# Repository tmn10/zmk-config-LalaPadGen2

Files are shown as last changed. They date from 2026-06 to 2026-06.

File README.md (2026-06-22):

# zmk-config-LalaPadGen2

LaLaPad Gen2 向け ZMK カスタムファームウェア設定。

---

## ハプティックフィードバック Mod

右トラックパッド下に DRV2605L + LRA を搭載し、ドラッグ開始・解除にクリック感を付与する。

### BOM

| 部品 | 型番 / 仕様 | 数量 | 備考 |
|---|---|---|---|
| LRA（横振動モーター） | JYLRA061228XH | 1 | 12×6×2.85mm、X軸、200Hz、定格 2.0V |
| ハプティックドライバ | DRV2605L | 1 | I2C 制御、アドレス 0x5A |
| 配線 | 細線（AWG30 相当） | 適量 | ケーブル引き回し穴（3×4mm）経由 |

### 配線

DRV2605L と Seeeduino XIAO BLE の接続：

| DRV2605L | XIAO BLE | 備考 |
|---|---|---|
| VDD | 3V3 | |
| GND | GND | |
| SDA | D4 (P0.26) | IQS9151 と I2C バス共有 |
| SCL | D5 (P0.27) | IQS9151 と I2C バス共有 |
| IN | GND | I2C モード使用のため不要 |
| OUT+ | LRA + | |
| OUT− | LRA − | |

IQS9151 IRQ ピン: XIAO D6 (P1.11)

### LRA ポケット寸法（3D プリント）

| 項目 | 値 |
|---|---|
| 内寸（L×W×D） | 12.2 × 6.2 × 2.8 mm |
| 底面厚 | 1.2 mm |
| ケーブル引き回し穴 | 3 × 4 mm |

各辺 0.1mm クリアランス（LRA 公称 12×6×2.85mm に対し深さ方向は 2.8mm で圧入気味）。

### 組み立てノート

- **ケース印刷**: リポジトリの `LRA_case.stl` を 3D プリントして使用する（推奨素材: PETG）
- **固定方法**: LRA ポケットの底面にカプトンテープを貼り、その上に両面テープで LRA を固定する
- **DRV2605L モジュール加工**: 基板上の FFC ケーブルコネクタは実装不要のため取り外してから使用すること

### ファームウェア設定

`lalapadgen2_right.overlay` の DRV2605L ノード：

```dts
drv2605: drv2605@5a {
    compatible = "ti,drv2605";
    reg = <0x5a>;
    actuator-type = "lra";
    rated-voltage-mv = <2000>;
    overdrive-voltage-mv = <2800>;
    library = <6>;
    status = "okay";
};
```

`lalapadgen2_right.conf` の主要ハプティック設定：

```conf
CONFIG_DRV2605=y
CONFIG_INPUT_IQS9151_HAPTIC_FEEDBACK_ENABLE=y
CONFIG_INPUT_IQS9151_HAPTIC_LONG_PRESS_EFFECT=6      # ドラッグ開始時
CONFIG_INPUT_IQS9151_HAPTIC_DRAG_LOCK_RELEASE_EFFECT=6  # ドラッグロック解除時
```

エフェクト番号は library 6（LRA）の 1〜117 から選択可能。`overdrive-voltage-mv` は XIAO BLE の 3.3V レール上限を超えないよう 3000mV 以下に抑えること。

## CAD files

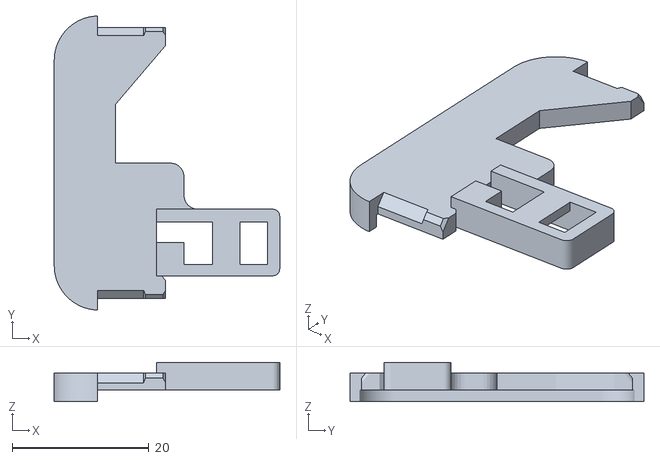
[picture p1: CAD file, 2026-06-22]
LRA_case.stl
33.0 x 43.0 x 5.71

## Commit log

2026-05-02 Disable USB logging due to conflict with studio-rpc-usb-uart snippet
2026-05-03 Enable drag lock via tmn10 fork of zmk-driver-iqs9151
    Point west.yml to tmn10/zmk-driver-iqs9151 fork (which adds drag-lock
    support) and enable CONFIG_INPUT_IQS9151_DRAG_LOCK_ENABLE on both
    trackpad shields.
2026-05-04 Disable 2F_TAP to test right-click false-positive
    Test whether spurious right clicks during rapid 1F tapping
    are caused by transient 2F detection firing BTN_1.
    Keep 2F_PRESSHOLD_ENABLE=y for Fusion drag use case.
2026-05-04 Disable 3F_TAP to test middle-click false-positive
    After disabling 2F_TAP, transient 3F detection now fires BTN_2.
    Same finger-count-noise pattern. Keep 3F_PRESSHOLD_ENABLE=y for
    existing 3-finger drag use case.
2026-05-04 Trigger rebuild for finger_count debounce driver update
    Pull in zmk-driver-iqs9151 main containing finger_count debounce
    that filters single-frame IC flickers. Should resolve TapDrag
    spuriously transitioning to 2F scroll.
2026-05-04 Disable finger_count debounce: design unsuitable for event-driven IC
    Driver is interrupt-driven (DRDY); IC only emits frames on events,
    so a fast tap is just touchdown + lift = 2 frames. Frame-count
    debounce with THRESHOLD=2 masks both, killing the tap entirely.
    Disable until redesigned with a scoped approach (only filter
    1->{2,3} flickers, leave 0<->1 transitions untouched).
2026-05-04 Re-enable finger_count debounce (now scoped to 1F flickers only)
    Driver-side debounce has been narrowed to only filter stable=1 to
    raw>=2 transitions, leaving 0<->1 transitions untouched. Taps will
    no longer be destroyed by the debounce. Drop the override line so
    default ENABLE=y applies.
2026-05-04 Re-enable 2F_TAP for right-click gesture
    Scoped finger_count debounce filters transient 1->2 flickers, so
    2F TAP no longer false-fires during 1F gestures. Restore 2F TAP
    to enable two-finger tap = right click.
2026-05-04 Re-enable 3F_TAP for middle-click gesture
    Same scoped debounce coverage as 2F_TAP — transient 1->3 flickers
    are now filtered, so 3F TAP no longer false-fires during 1F gestures.
2026-05-04 Drop TANG_DRAG_ENABLE override (option removed from driver)
    Driver removed the TANG TapDrag feature; the explicit =n override
    is no longer a valid Kconfig key.
2026-05-04 Temporarily disable debounce for hardware diagnostic
    Disable to expose raw IC finger_count flickers; compare left vs
    right trackpad under rapid 1F tapping to verify if flicker is
    hardware-localized (PCB issue) or universal (IC behavior).
2026-05-04 Re-enable debounce after hardware diagnostic
    Confirmed via diagnostic: right shield emits more finger_count
    flickers than left under rapid 1F tapping. Localized hardware
    issue (PCB/solder/IC variation) on the right side. Scoped debounce
    acts as effective software mitigation.
2026-05-05 Enable 1F long-press hold engagement
    Hold a single finger statically for 500ms (default) -> BTN_0 hold
    engages, allowing drag-on-hold without the TapDrag pre-tap.
    TapDrag still works for wide-area drags where reach is limited.
2026-05-05 Rename to LONG_PRESS_HOLD_ENABLE; long-press hold now applies to 1F/2F/3F
    Driver renamed CONFIG_INPUT_IQS9151_1F_LONG_PRESS_HOLD_ENABLE to
    CONFIG_INPUT_IQS9151_LONG_PRESS_HOLD_ENABLE since the engagement logic
    is shared across all finger counts. 2F engages BTN_1 hold, 3F engages
    BTN_2 hold under the same time/movement criteria.
2026-05-05 Tune LONG_PRESS_HOLD_MS to 300ms (default 500)
    Faster engagement for drag-on-hold. Trade-off: shorter window
    between "hold finger still" and BTN_0 press; reduces accidental
    holds is less likely too because TAP_MAX_MS is 250ms (taps still
    lift before this).
2026-05-05 Make finger_count debounce explicit (driver default flipped to n)
    Driver upstream default for FINGER_COUNT_DEBOUNCE_ENABLE was changed
    from y to n; all opt-in features now require explicit =y at the
    board/shield level.
2026-05-06 Trigger rebuild for drag-lock release-tap click toggle
    Driver gained CONFIG_INPUT_IQS9151_DRAG_LOCK_RELEASE_TAP_CLICK_ENABLE
    (default n). Pull in the new behavior so drag-lock release-tap is
    silent (no click), matching the user's multi-select + grab + move
    workflow where the click would deselect.
2026-05-06 Trigger rebuild for finger_count debounce scope expansion
    Driver expanded scoped debounce to cover all upward transitions
    during an active multi-finger session (stable>=1 to raw>stable).
    Suppresses 2F -> 3F flickers that misfire 2F long-press hold as
    3F middle-click hold.
2026-05-06 Trigger rebuild for long-press cross-finger override fix
    Driver gates long-press hold engagement on drag_lock_button==0,
    preventing the 2F-hold -> partial-lift -> 1F-hold-cascade override
    that fired BTN_0 on top of a latched BTN_1 drag-lock.
2026-05-14 Enable DRV2605L haptic feedback on right shield
    Right side only: DRV2605L on the existing xiao_i2c bus at 0x5A drives
    the Vybronics VG1040003D LRA embedded in the trackpad case lid. Effects
    are configured for tap (1=Strong Click), long-press hold engagement
    (47=Buzz 1), drag-lock arm (10=Double Click) and drag-lock release
    (7=Soft Bump). Defaults can be tuned via Kconfig.
2026-05-21 haptic: weaker tap, double-bump for drag-lock, 300ms buzz interval
    - TAP: 3→9 (Soft Bump 30%, was Strong Click 30%)
    - DRAG_LOCK_ARM: 8→11 (Double Click 60%, for 2-bump feel)
    - DRAG_LOCK_RELEASE: 0→11 (Double Click 60%, was disabled)
    - DRAG_BUZZ_INTERVAL: 100→300ms
2026-05-21 haptic: disable drag buzz, sharper double-click for drag-lock
    - DRAG_BUZZ_EFFECT=0 (disabled — was causing spurious 2nd tap vibration)
    - DRAG_LOCK_ARM/RELEASE: 11→10 (Double Click 100%, crisper feel)
2026-05-21 haptic: soften drag-lock arm/release to Effect 11 (Double Click 60%)
2026-05-21 haptic: tighten drag-lock release window, soften arm/release effects
    - DRAG_LOCK_RELEASE_TAP_MOVE: 50→10 (prevent mid-drag lifts from
    being treated as release taps — root cause of unwanted vibration)
    - ARM/RELEASE effect: 11→9 (Soft Bump 30%, weakest single bump;
    Double Click 60% was too strong per user feedback)
2026-05-21 haptic: try Effect 62 for tap, Effect 30 for drag-lock arm/release
    - TAP: 9→62 (遷移クリック5 - 20%, subtler than Soft Bump 30%)
    - DRAG_LOCK_ARM/RELEASE: 9→30 (短く強いダブルクリック4 - 30%, weakest double)
2026-05-21 haptic: tap=9, long-press=30, drag-lock-arm=off, release=30
2026-05-22 config: increase long-press hold threshold 500→750ms
2026-05-25 feat: wire FSR click and 2F drag-suppression (hardware disabled)
    Add ADS1015, fsr_click, fsr_click_listener nodes and fsr-click-dev
    phandle on iqs9151. All FSR nodes are status="disabled" and conf
    entries commented out until hardware is installed.
    To enable: uncomment CONFIG_ADC/ADS1X1X/INPUT_FSR_CLICK in right.conf
    and set the three nodes to status="okay" in right.overlay.
2026-05-26 fix: inline ADS1X1X_INPUT_AIN0 instead of including ads1x1x.h
    The dt-bindings/adc/ads1x1x.h header is not available in ZMK v0.3's
    Zephyr toolchain. Define ADS1X1X_INPUT_AIN0 = 4 (single-ended AIN0)
    directly in the overlay to avoid the missing-header build failure.
2026-05-28 config: reduce right trackpad scroll speed to 2/3 (1/40 → 1/60)
2026-05-30 fix: raise iqs9151 init priority to 95 for FSR dependency order
    check_init_priorities requires: ADS1015(80) → fsr_click(90) → iqs9151.
    Default iqs9151 priority 80 conflicts with fsr_click 90 since iqs9151
    depends on fsr_click via DTS phandle.
2026-05-31 Disable 1F_PRESSHOLD, set HoldDrag threshold to 500ms
    1F_PRESSHOLD (tap-then-retouch within 300ms to drag) caused false
    drag triggers. Switching to HoldDrag-only (hold finger 500ms) for
    clearer drag intent. DragLock remains enabled.
2026-06-04 fix(trackpad): 左パッドのカーソル/スクロール速度を右に合わせる
    trackpad_listener_L の通常モードのスケーラを listener_R と一致させる
    (zip_xy_scaler 2 3, zip_scroll_scaler 1 60)。lowspeedmode は左右一致のため変更なし。
2026-06-07 haptic: increase overdrive to 2800mV and switch to effect 5 for new LRA
2026-06-07 haptic: switch to effect 4
2026-06-07 haptic: switch to effect 3
2026-06-22 docs: add README with haptic mod BOM, wiring, and pocket dimensions
    左側のドラッグ（LONG_PRESS_HOLD / DRAG_LOCK）も無効化。
2026-06-22 assets: add LRA pocket case STL
    [LRA_case.stl]
2026-06-22 docs: add assembly notes to haptic mod section
    STL印刷・カプトン+両面テープ固定・FFCコネクタ除去の注記を追加。
2026-08-17 feat(keymap): 3本指横スワイプを Spaces 切替(⌃←/⌃→)に統一
    左パッド=タブ切替、右パッド=戻る/進む で食い違っていた3本指の横スワイプを
    左右とも Mission Control のスペース移動に揃える。
    戻る/進むは右パッドの2本指横スワイプへ移設する（別コミット）。
2026-08-17 feat(trackpad): 右パッドの2本指横スワイプを戻る/進むに割り当て
    ドライバ側で追加した2本指横スワイプ(BTN_8/9)を受けるため、
    仮想キー枠を68〜71に増設して左右パッドぶんを確保する。
    右パッドは横スクロールを捨てて横軸をスワイプに明け渡し、
    ⌘←/⌘→ を割り当てる。左パッドは横スクロールを維持する。
2026-08-26 fix(combos): スクショ2種に⌃を追加、escapeのキー位置重複を修正
    screenshot/screen_capture を ⌘⇧⌃4 / ⌘⇧⌃5 に変更する。
    escape は key-positions が <0 0 1> で位置0が重複しており、
    同じキーを2回押すことはできないため永久に発火しなかった。
    <0 1>（Q + W）に修正する。
2026-08-27 fix(combos): screen_capture を ⌘⇧5 に戻す
    ⌃⇧⌘5 は macOS に存在せず空振りしていた。
    ⌃でクリップボードに切り替わるのは3と4だけで、
    5はツールバーを開くUIのため⌃付きの派生がない。
    画面収録もツールバー経由でしか始められない。
2026-09-22 fix(layout): 2Fスワイプ枠の row を 7 にし行番号の逆戻りを解消
    d8bc43e で 68〜71 を追記した際、直前が row 6 なのに row 5 のまま
    足したため行番号が逆戻りし、keymap-editor が InfoValidationError で
    リポジトリを開けなくなっていた。
    この row/col は devicetree の RC() とは別物で、keymap-editor が
    bindings を (row, col) 順にテキストへ書き戻すための並び順を決める。
    逆戻りしたままだと保存時にバインディングが入れ替わるため、
    弾かれていたのは正しい挙動。
    独立した row 7 に移し、col は他行と同じく x に揃えた。
    (row, col) のソート順が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
2026-10-25 feat(keymap): 右の十字キーで Rectangle のウィンドウ整列、中央との同時押しは &word に寄せる
    上=最大化(⌃⌥↩)・左=左半分(⌃⌥←)・下=元に戻す(⌃⌥⌫)・右=右半分(⌃⌥→)。
    押し込み時に方向も入る誤爆は、中央+方向が80ms以内なら &word だけ出す combo で吸収（既定レイヤーのみ）。
2026-10-26 fix(keymap): 十字キーの押し込みで窓が動く誤爆を、離したときに出す方式で止める
    80ms の同時押し combo では間に合わなかった。
    - 上下左右は hold-tap(tap-unless-interrupted, 300ms)：離したときに整列を出し、押している間に中央が入れば何も出さない
    - &word は押している間 NO_DIR レイヤー(5)を保ち、中央が先に入ってから傾いても方向を無効にする
2026-10-26 fix(keymap): 左パッドのシングルタップ(⌘R)を無効にする
2026-10-26 feat(keymap): 右下の矢印を逆T字に（↑を .: と入れ替え、下段を ← ↓ →）
2026-10-29 revert: 右下の矢印を元の並びに戻す（逆T字は慣れなかった）
    This reverts commit 5f30974.
2026-10-31 feat(keymap): 右⌘の親指キーに音声入力の2段を足す（長押し=右⌘／タップして押し続ける=右⌥）
    VoiceInk で右⌘=AI なし、右⌥=AI で整える、に割り当てるため。
    タップ=かな・長押し=右⌘の挙動は tap-dance の1段目にそのまま残す。
